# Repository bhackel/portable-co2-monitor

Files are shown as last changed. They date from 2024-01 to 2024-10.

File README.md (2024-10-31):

# portable-co2-monitor

## View an updated log on my website
https://brycehackel.me/posts/1728693895830-portable-co2-monitor-version-0.5/

## Overview

Recent research has shown possible correlations between high CO2 concentration in indoor environments and decreased cognitive function. As someone that is curious about optimizing my brain for productivity, I wanted to investigate this correlation.

This idea started when I attended an office hour for my algorithms class. This took place in a very small room, packed full of students. I immediately felt the thickness of the air in the room, and shortly after, lost focus and forgot my question. I left for a bit to reconcentrate, believing that I might be tired from a lack of sleep. However, when I went back into the room, I lost my focus once again. I heard about CO2 fatigue from a YouTube video and was curious about it.

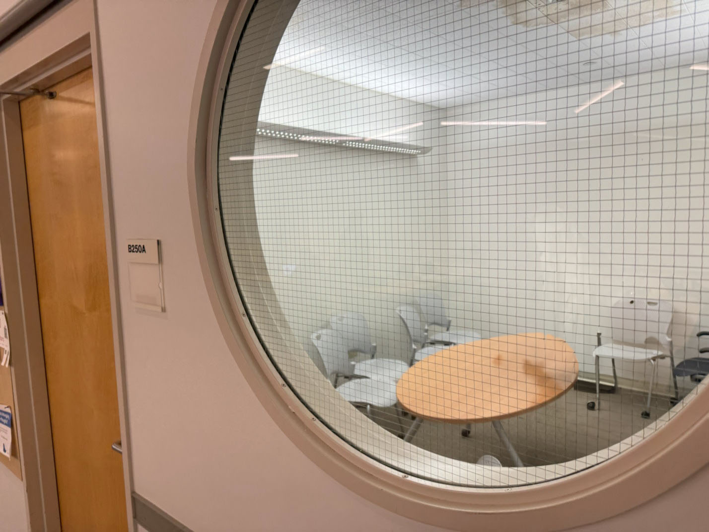
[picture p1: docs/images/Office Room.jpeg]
Office Hour Room


I looked around on Amazon for a cheap monitor, but the majority of the devices I found were above $100 (there are a lot of new devices below $40 now). I was not willing to spend so much money on a curiosity, so I decided to look for a cheap alternative.

## V0 Prototype Design

I looked on AliExpress to see if I could find a cheap sensor to use. I quickly found the SenseAir S8 for around $20, and decided to buy one.

I used a spare Arduino Nano 33 IoT that I had on hand and attempted to connect it to the SenseAir S8. I found [this article](https://karlduino.org/CO2monitor/) describing how someone else connected their Arduino to this sensor, so I followed their process to create my code. I had to slightly modify the code to work with the hardware serial connections instead of using the SoftwareSerial package, but otherwise had minor issues.

After verifying that the sensor works, I decided to begin designing ways to make the device more portable. This began with a CAD model.

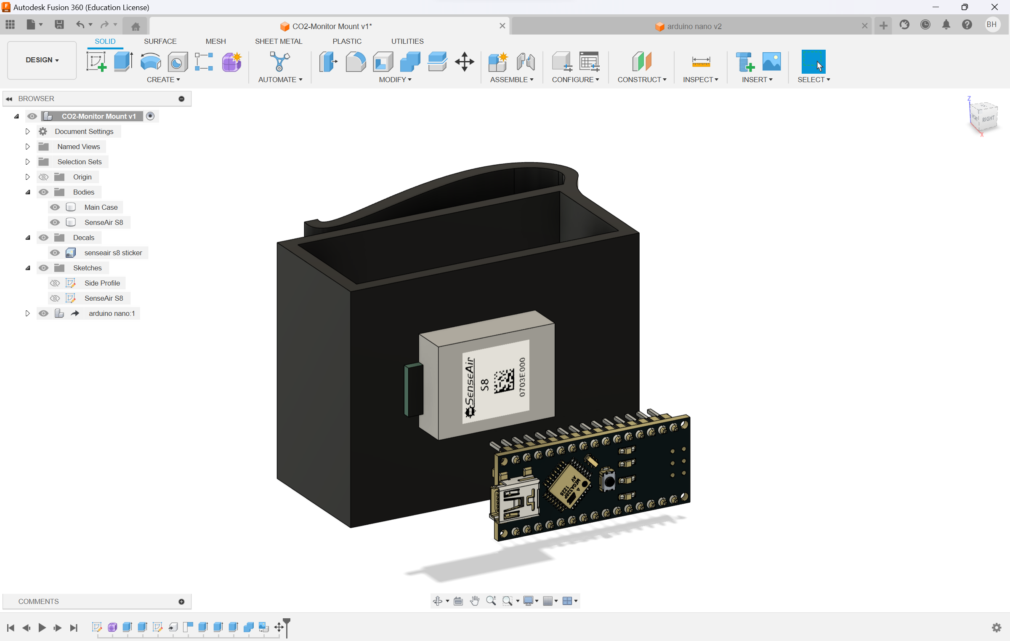
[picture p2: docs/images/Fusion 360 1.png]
Fusion 360 Image


My goal here was to try to visualize the parts so that I could think of ideas on how to integrate everything. I printed this at my local makerspace and proceeded with integration.

I roughly put the parts on a sheet of perfboard and measured out the width that I decided on for my CAD model. Everything seemed to fit, so I proceeded to cut the board.

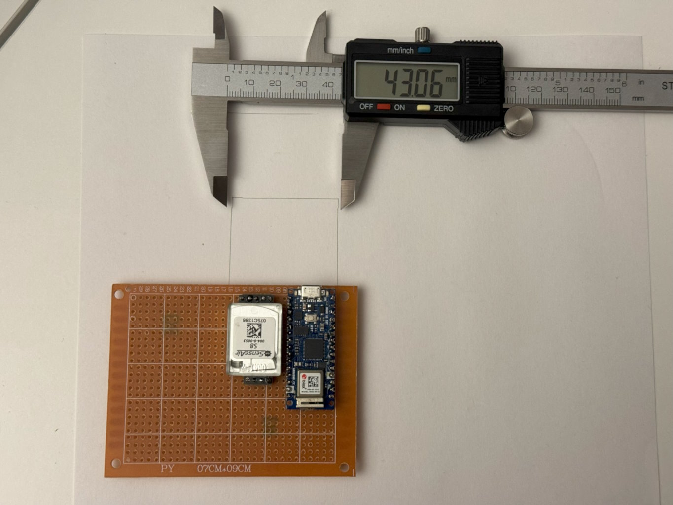
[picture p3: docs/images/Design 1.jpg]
Perfboard Design


I decided to flip the CO2 sensor because the foam diffuser needs access to air, and I planned to face this towards the side of the mount.

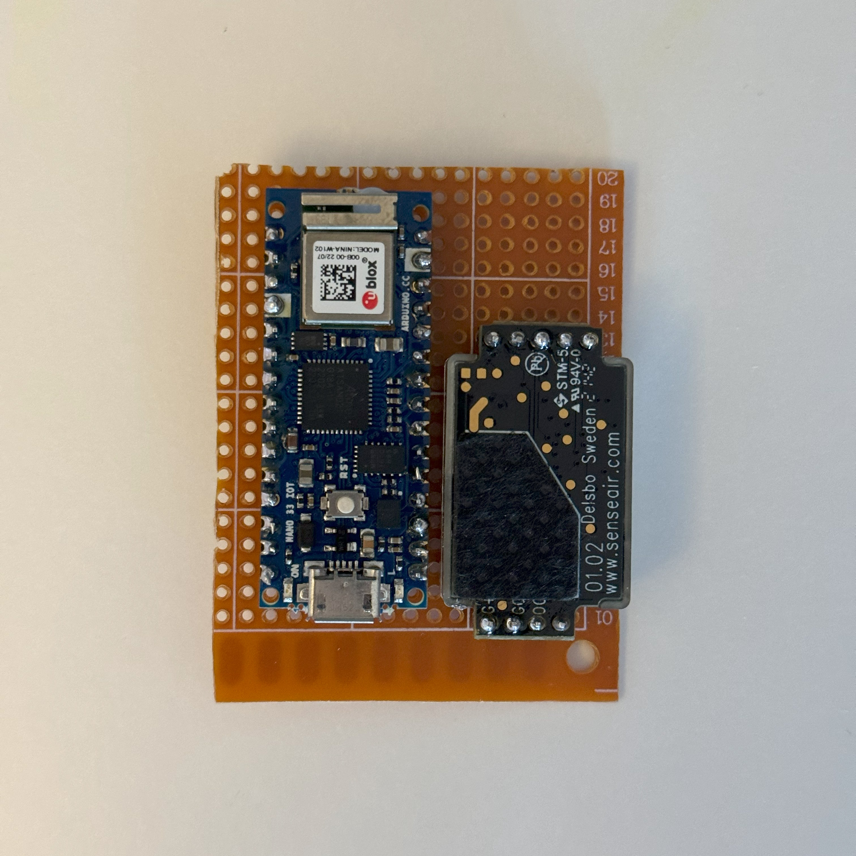
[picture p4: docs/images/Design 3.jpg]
Cut Perfboard with parts


I connected up the pins of the Arduino and the CO2 sensor using solder and wires. Yes, I lack good soldering skills.

The wiring is as follows

- Green Wire: Arduino TX Pin <-> SenseAir S8 RX Pin
- Blue Wire: Arduino RX Pin <-> SenseAir S8 TX Pin
- Red Wire: Arduino VUSB <-> SenseAir S8 G+ Pin
- Black Wire: Arduino GND <-> SenseAir S8 G0 Pin

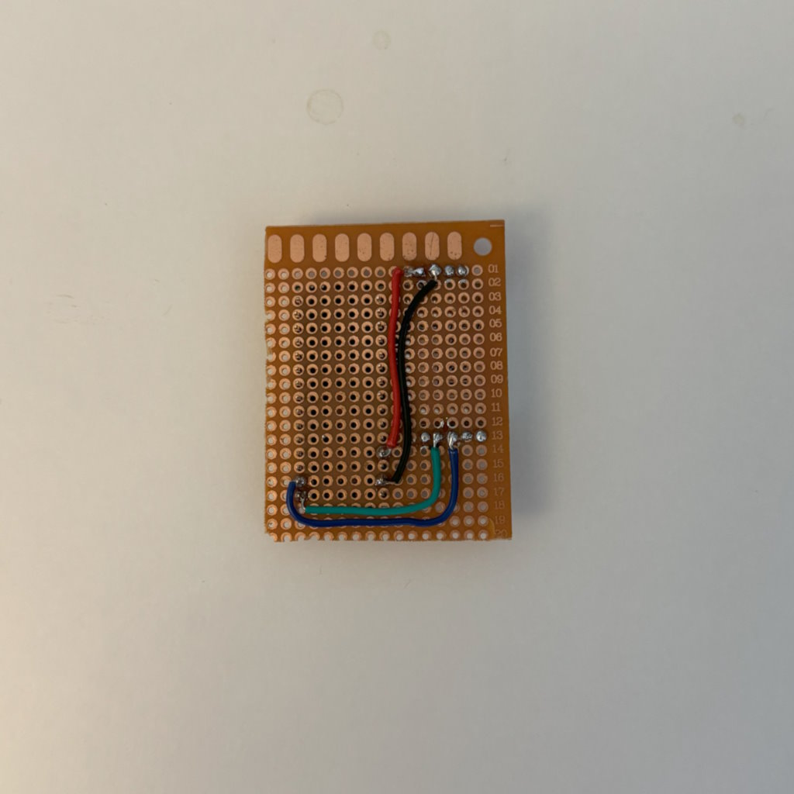
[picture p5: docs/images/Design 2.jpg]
Back side of perfboard with soldered wires


The next step was to somehow mount the board into the case. However, although I was planning on powering the device over USB, I realized at this point that this was not feasible because of a lack of space. I then decided to cut a broken USB cable and solder it directly to the board.

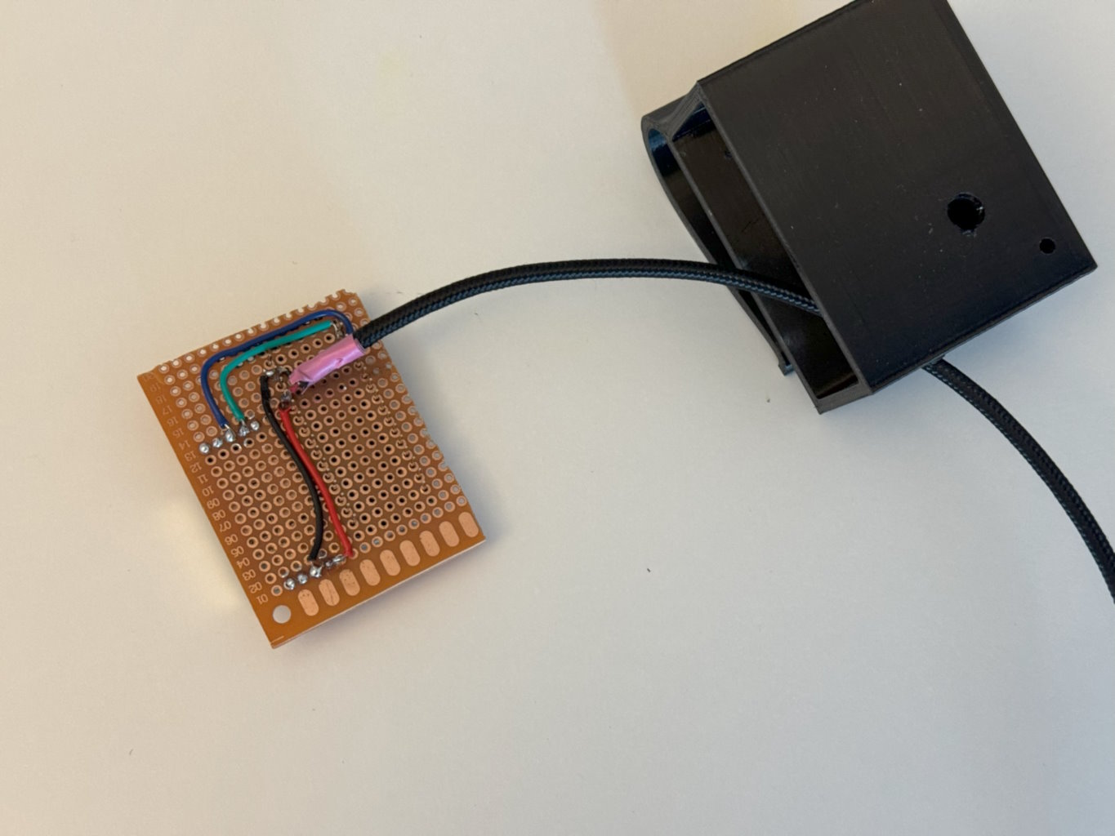
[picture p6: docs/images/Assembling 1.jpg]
Board and mount with USB cable


Next was to shove the board into the case and mount it somehow. I decided to put a screw through the case and the board, and then attach it with a washer.

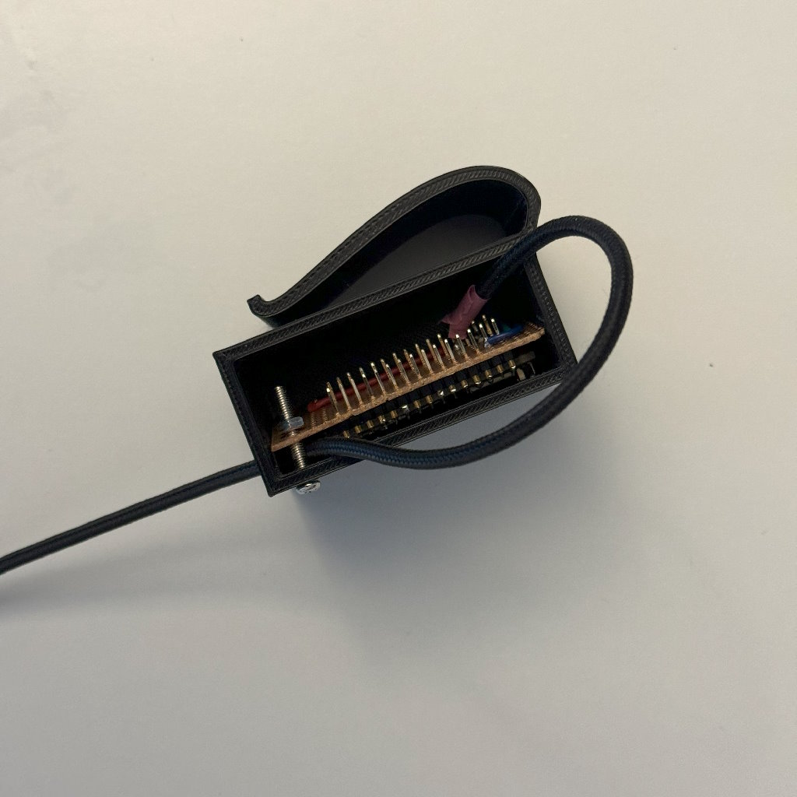
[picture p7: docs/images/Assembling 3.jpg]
Board inside of case


After using some very ugly hot glue to attach the side panel of the case, I ended with the final design.

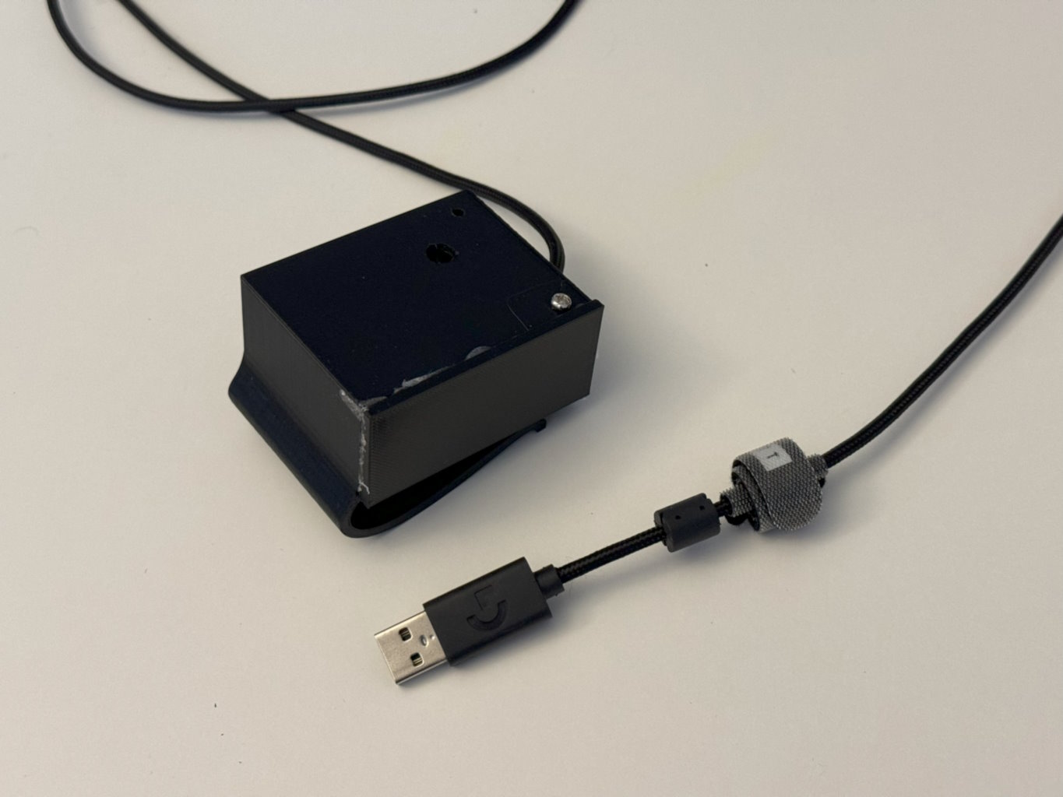
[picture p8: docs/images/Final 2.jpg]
Completed build

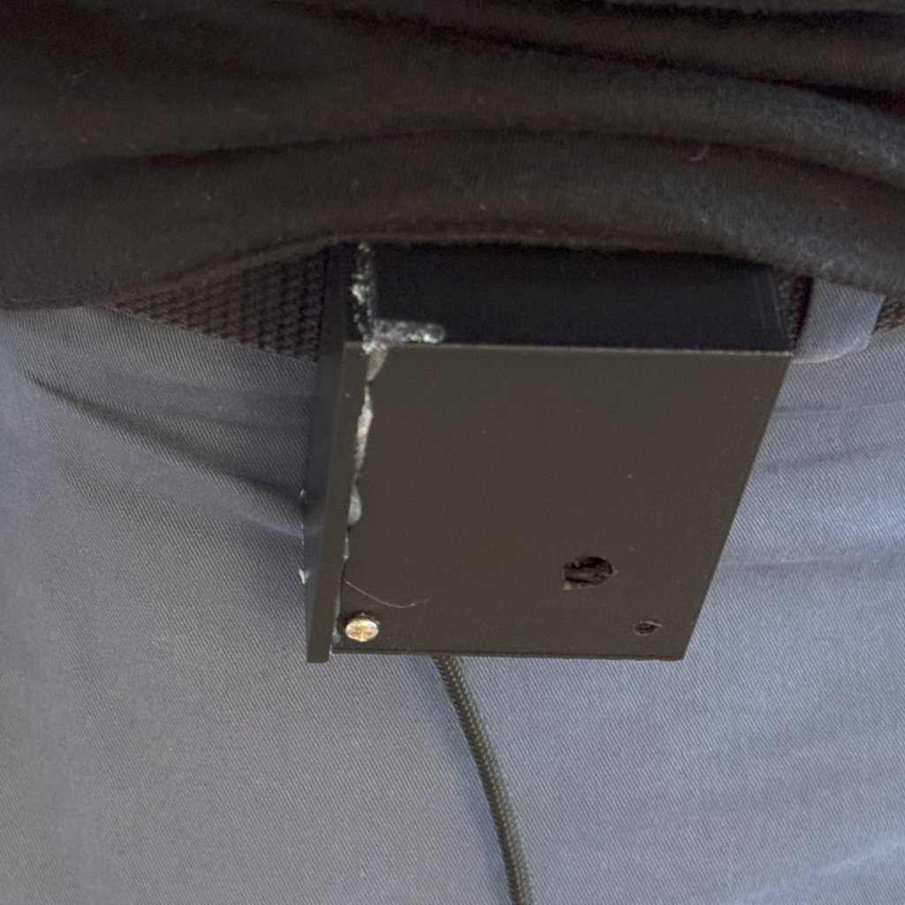
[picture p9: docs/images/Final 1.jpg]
Completed build on belt


## iOS App

The second half of this project involves an accompanying iOS app that connects to the device over Bluetooth.

More to come later

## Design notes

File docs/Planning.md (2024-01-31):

This is the first project where I took the time to think through an ideal version of a CO2 monitor, then I broke it down into small pieces and will be attempting to execute on it

Full End-To-End project
 - IOS App that can sync data from the device
 - Device that monitors CO2 levels, can be attached to person

Software requirements:
- IOS App
	- Want to build in swift
	- Needs to connect to the device over bluetooth, then read some stored data, then clear the stored data on the device, and store it in  app
	- Display a graph that shows CO2 exposure over the day
	- Export button to download CSV with "time: ppm" values
- Microcontroller code
	- Possibly translate it into Rust
	- data should be collected every 30? seconds
	- Poll the Senseair using raw Serial comms
	- First develop on arduino 33 iot
	- Then create PCB design with the components
	- This must happen before 3D print can be done

Hardware requirements:
- Option 1: Wrist
	- 3D print a decently big rectangle that attaches to the wrist using Velcro
	- Power using a wire to a battery bank (need 5V), or integrate battery somehow
	- This seems like the ultimate option, copy a Fitbit in design. highest difficulty
- Option 2: Belt hook
	- 3D print a box that clips onto the belt
	- Power using a wire to a battery bank that is in pocket
	- This is where I should start

Procedure
- We already have a working CO2 monitor
- #### ARDUINO
- Add Bluetooth functionality so that I can connect to it with my laptop and read the current CO2 value
- Add Bluetooth functionality so that I can connect to it, read up to the past 100 values, then these values are cleared from a storage in memory
- #### APP
- Create a swift Hello World app and send it to my phone
- Add Bluetooth functionality to the swift app so that it can connect to the Arduino and read the current CO2 value to the screen
- Have it continually read the CO2 value and put it on the screen
- Have it read the past 100 values
- Create a storage for storing CO2 values over time
- Create a graph that shows these values
- Create a table that shows these values
- Create a button that allows to share a CSV with these values
- #### PCB
- Design a PCB that integrates all the components nicely
- Make sure to figure out how to get that microcontroller into there
- Somehow get the power connected with a connector
- I am unfamiliar in this part
- #### 3D Printing
- Create a box that encases the PCB and has poles or something to mount it on
- Don't be lazy and use zipties, make this look professional with screw mounts

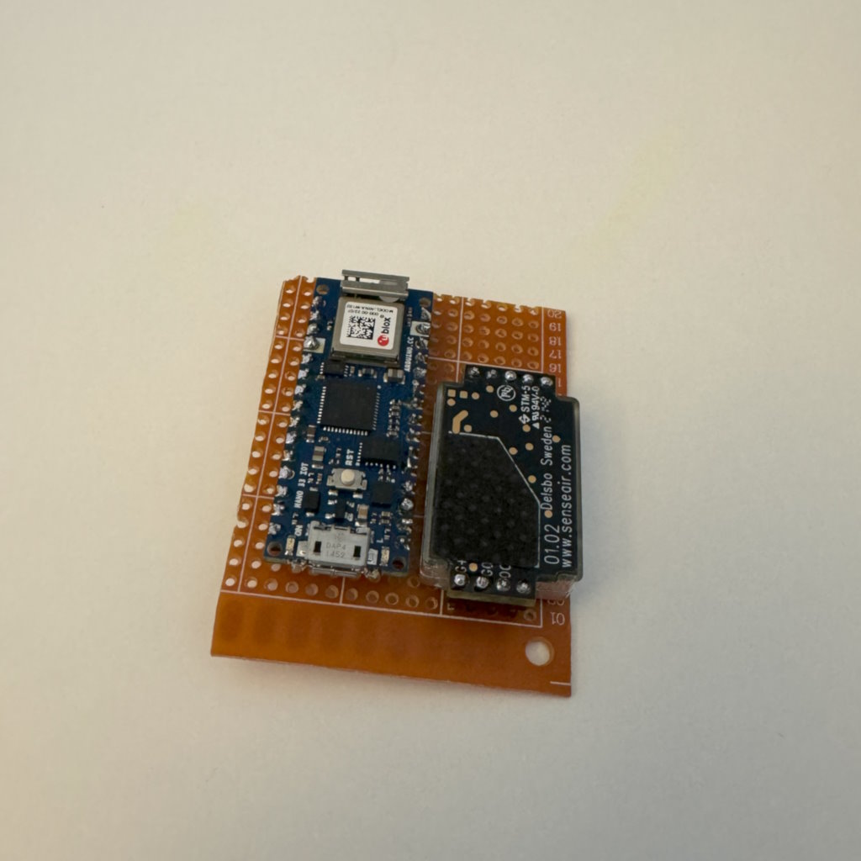
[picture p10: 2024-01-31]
docs/images/Design 4.jpg

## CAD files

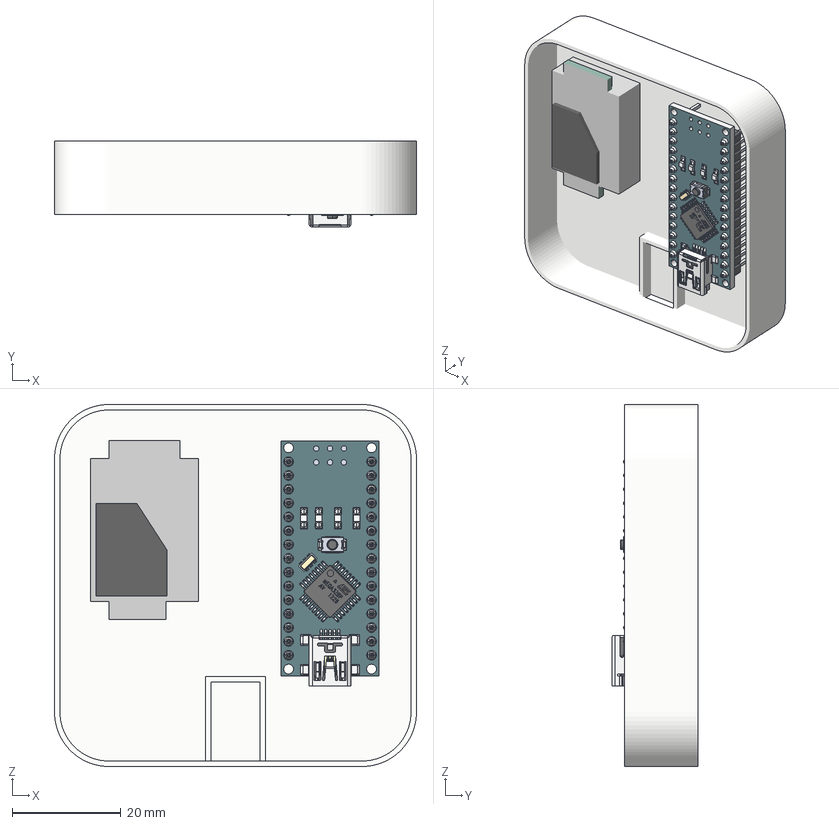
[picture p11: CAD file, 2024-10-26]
3d-models/V0.5/MagSafe CO2 Monitor.3mf
66.5 x 15.8 x 66.5 mm
SenseAir S8

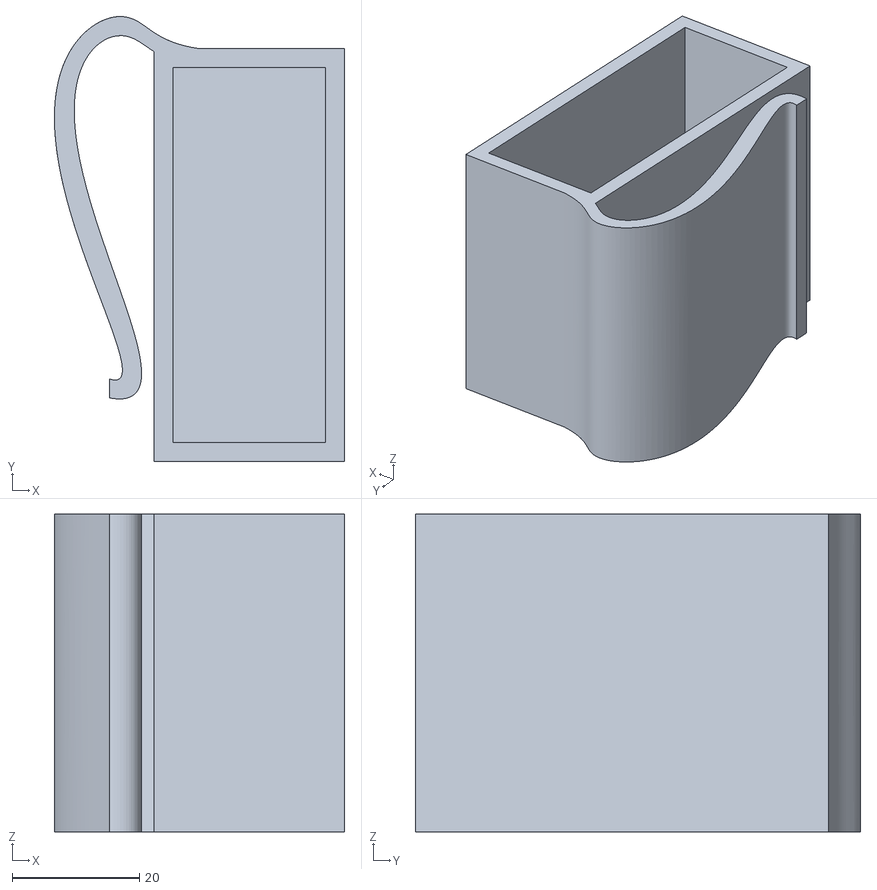
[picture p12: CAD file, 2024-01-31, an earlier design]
3d-models/V0/Main Case.stl
45.7 x 70.0 x 50.0

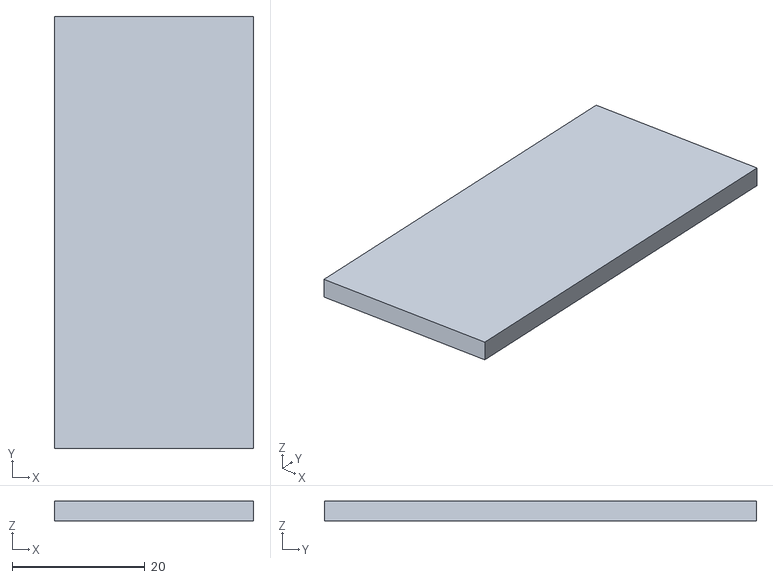
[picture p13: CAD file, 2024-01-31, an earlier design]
3d-models/V0/Side Panel.stl
30.0 x 65.0 x 3.00

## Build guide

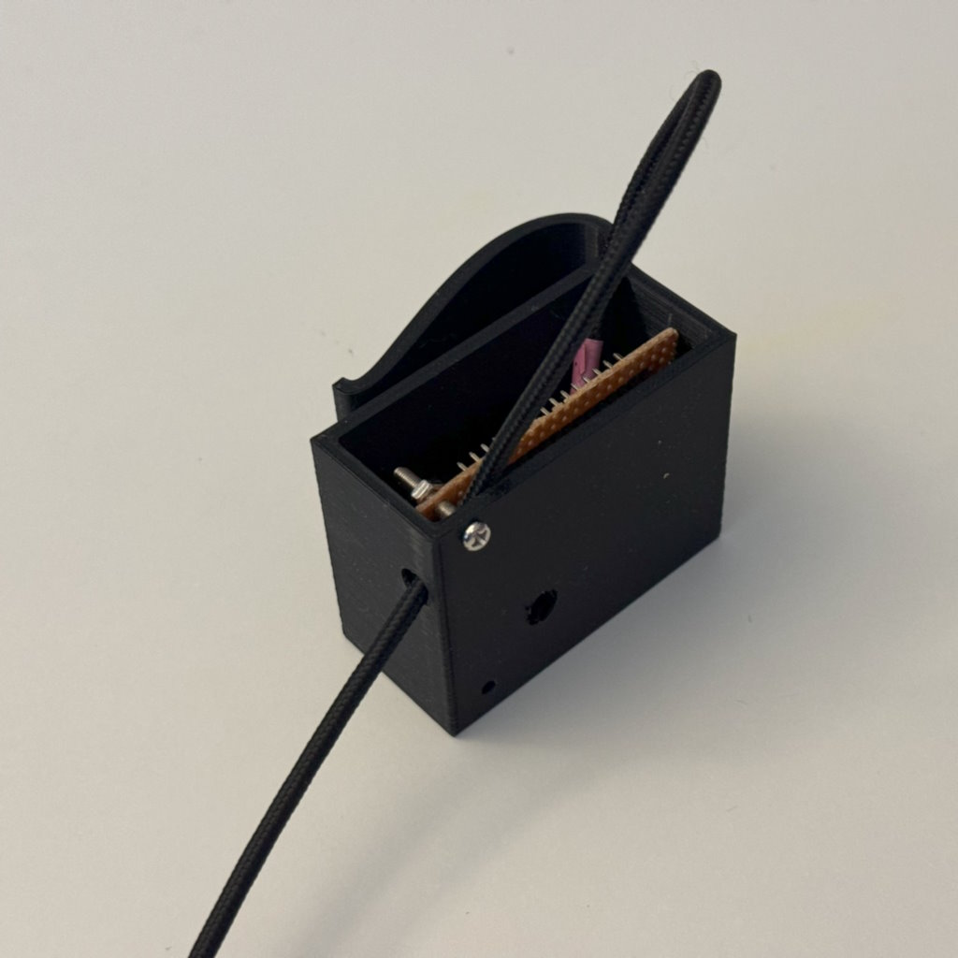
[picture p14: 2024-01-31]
docs/images/Assembling 2.jpg

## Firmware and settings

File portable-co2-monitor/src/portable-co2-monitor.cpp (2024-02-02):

// Portable CO2 monitor with Senseair S8

#include <Arduino.h>
#include "s8_uart.h"

#include "portable-co2-monitor.h"


S8_UART *sensorS8;
S8_sensor sensor;

int maxCo2 = 0;
double avgCo2 = 0.0;
unsigned long numMeasurements = 0;
int lastMeasurementTime = 0;
int curTime = 0;

// Set up BLE services and characteristics
BLEService co2Service("FA11B9C1-426C-485B-8184-03EC0E0741EC");
BLEIntCharacteristic co2CurLevelCharacteristic("FA116969-426C-485B-8184-03EC0E0741EC", BLERead | BLENotify);
BLEIntCharacteristic co2MaxLevelCharacteristic("FA116970-426C-485B-8184-03EC0E0741EC", BLERead | BLENotify);
BLEIntCharacteristic co2AvgLevelCharacteristic("FA116971-426C-485B-8184-03EC0E0741EC", BLERead | BLENotify);
BLEService ledService("8370846E-2189-44BC-86F9-76FD3772BA84");
BLEIntCharacteristic ledStatusCharacteristic("83706969-2189-44BC-86F9-76FD3772BA84", BLEWrite);

void setup() {
  // Set up Serial for logging
  Serial.begin(9600);
  Serial.println("Starting up...");

  // Set up BLE services and characteristics
  while (!BLE.begin()) {
    Serial.println("Waiting for BLE to start");
    delay(1);
  }
  BLE.setLocalName("CO2Monitor");
  BLE.setAdvertisedService(co2Service); // sets the primary service
  BLE.addService(co2Service);
  co2Service.addCharacteristic(co2CurLevelCharacteristic);
  co2Service.addCharacteristic(co2MaxLevelCharacteristic);
  co2Service.addCharacteristic(co2AvgLevelCharacteristic);
  co2CurLevelCharacteristic.setEventHandler(BLERead, co2CurLevelCharacteristicRead);
  co2MaxLevelCharacteristic.setEventHandler(BLERead, co2MaxLevelCharacteristicRead);
  co2AvgLevelCharacteristic.setEventHandler(BLERead, co2AvgLevelCharacteristicRead);
  BLE.advertise();

  // Initialize UART connection and S8 sensor
  Serial1.begin(S8_BAUDRATE);
  sensorS8 = new S8_UART(Serial1); 

  // Check if S8 sensor is available by reading firmware version
  sensorS8->get_firmware_version(sensor.firm_version);
  int firmwareStrLen = strlen(sensor.firm_version);
  int numTries = 1;
  int s8AttemptsLimit = 120;
  while (firmwareStrLen == 0 && numTries++ < s8AttemptsLimit) {
      delay(250);
      sensorS8->get_firmware_version(sensor.firm_version);
      firmwareStrLen = strlen(sensor.firm_version);
  }

  // Log basic S8 sensor info
  Serial.println("SenseAir S8 Firmware:");
  if (firmwareStrLen == 0) Serial.print("N/A");
  else Serial.println(sensor.firm_version);
  sensor.sensor_id = sensorS8->get_sensor_ID();

  Serial.println("Bluetooth device active, waiting for connections...");
}

void loop() {
  // Check if a device (central) connects to this device (peripheral)
  BLEDevice central = BLE.central();
  if (central) {
    Serial.print("Connected to ");
    Serial.println(central.address());
    while (central.connected()) {
      // Check if enough time has passed since last check
      curTime = millis();
      if (curTime <= (lastMeasurementTime + MEASUREMENT_INTERVAL)) {
        continue;
      }
      lastMeasurementTime = millis();

      
      char printBuffer[17];
      // Get current CO2 measurement
      sensor.co2 = sensorS8->get_co2();
      sprintf(printBuffer, "%4d", sensor.co2);
      Serial.println("CO2: " + String(printBuffer));
      // Caulcualte max since start-up
      if (sensor.co2 > maxCo2) { 
        maxCo2 = sensor.co2; 
      }
      sprintf(printBuffer, "%-4d", maxCo2);
      Serial.println("Max: " + String(printBuffer));
      // Calculate average CO2 level
      if(numMeasurements == 0) {
          avgCo2 = (double) sensor.co2;
      } else {
          avgCo2 = (avgCo2 * (double)numMeasurements + (double)sensor.co2) / (double)(numMeasurements + 1);
      }
      numMeasurements++;
      int avgCo2Int = round(avgCo2);
      sprintf(printBuffer, "%4d", avgCo2Int);
      Serial.println("Ave: " + String(printBuffer));

      // Update LED state
      if (ledStatusCharacteristic.written()) {
        Serial.println("LED status changed");
        int status = boolean(ledStatusCharacteristic.value()) ? HIGH : LOW;
        digitalWrite(LED_BUILTIN, status);    
      }

      // Update BLE characteristics
      co2CurLevelCharacteristic.writeValue(sensor.co2);
      co2MaxLevelCharacteristic.writeValue(maxCo2);
      co2AvgLevelCharacteristic.writeValue(avgCo2Int);
    }
  }
}

/* Read request handler for characteristics */
void co2CurLevelCharacteristicRead(BLEDevice central, BLECharacteristic characteristic) {
  co2CurLevelCharacteristic.writeValue(sensor.co2);
}
void co2MaxLevelCharacteristicRead(BLEDevice central, BLECharacteristic characteristic) {
  co2MaxLevelCharacteristic.writeValue(maxCo2);
}
void co2AvgLevelCharacteristicRead(BLEDevice central, BLECharacteristic characteristic) {
  co2AvgLevelCharacteristic.writeValue(round(avgCo2));
}

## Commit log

2024-01-17 CAD Revision 1
2024-01-31 Add V0 CAD Models
    [Main Case.stl, Side Panel.stl]
2024-02-02 Fix LED indicator bug
    [portable-co2-monitor.cpp]
2024-10-26 Add V0.5 CAD
    [MagSafe CO2 Monitor.3mf]
2024-10-31 Fix 8-bit BLE issue, remove LED code
